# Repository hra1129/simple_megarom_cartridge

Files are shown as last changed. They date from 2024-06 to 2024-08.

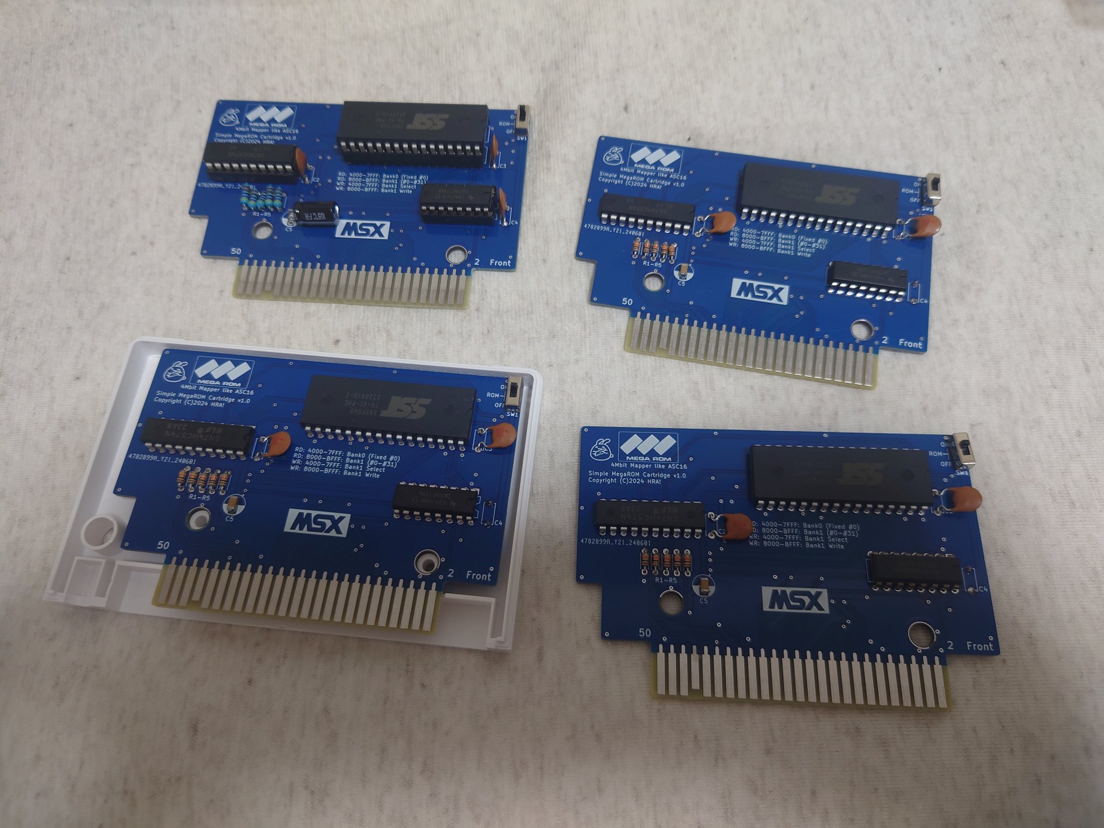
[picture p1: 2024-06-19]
image2.jpg

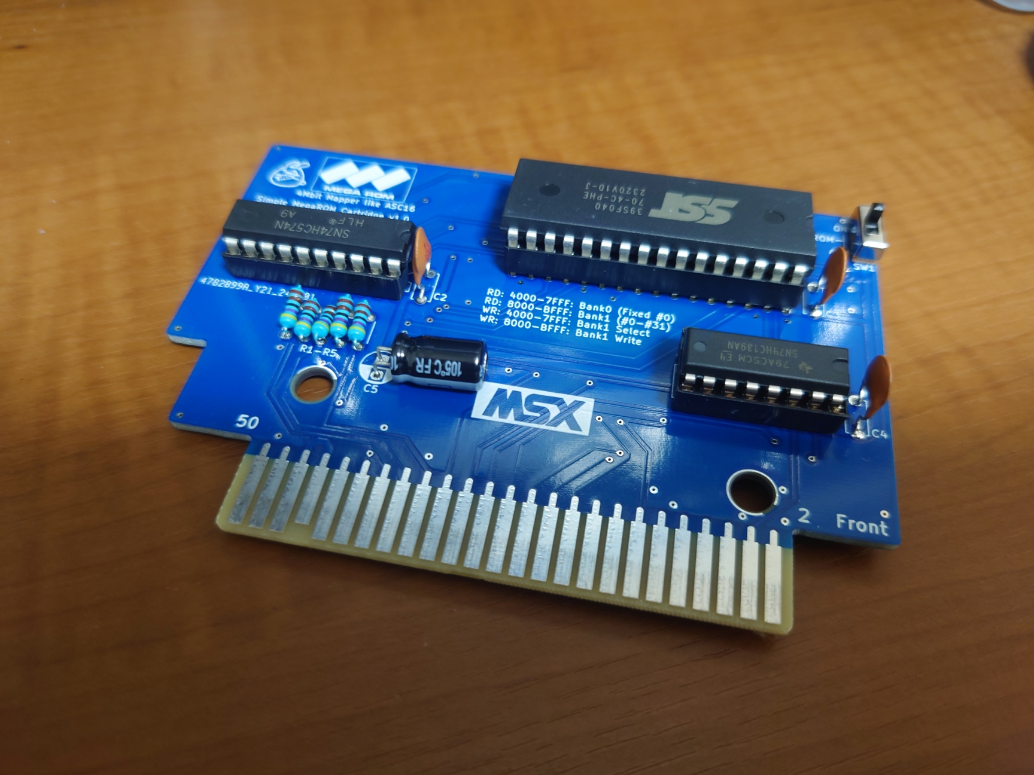
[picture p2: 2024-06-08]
image.jpg

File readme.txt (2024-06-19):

■概要
ASC16風のメガROMです。
ASC16風であって、ASC16ではないので、ASC16タイプの市販ゲームソフトを書き込んでも、
多くの場合、正常に動作しませんのでご注意下さい。
あくまで、自作ソフトを動かすためのメガROMコントローラーで、
安価に汎用部品で作りたい人向けです。

■免責事項
無保証です。
本情報に基づいた制作物に関して、何らかの不具合・不利益を被ったとしても、当方(HRA!/t.hara)は一切責任を負いません。
同意できる場合に限り、複製、改造等の派生、製造、配布、販売は自由に行って頂いて構いません。
動作確認などは各自で行った上で、各自の責任の下で配布・販売を行ってください。

■仕様
4000-7FFF が BANK0, 8000-BFFF が BANK1 になります。
BANK0への書き込みは、BANK1のバンクレジスタへの書き込みになります。
BANK1への書き込みは、BANK1のバンクレジスタの示すアドレスのROMへの書き込みになります。
BANK0の読み出しは、ROMのBANK#0の読み出しになります。
BANK1の読み出しは、BANK1のバンクレジスタの示すアドレスのROMの読み出しになります。
ROMのバンクは、BANK#0～#31 の 32通り。1バンク16KB になります。512KB の ROM の先頭から 16KBずつ区切り、
それを先頭から BANK#0, BANK#1, ... , BANK#31 と割り当てた番号になります。

C000-FFFF は BANK1のバンクレジスタのミラーになってます。ここに書き込んでもバンクが切り替わります。
といっても、通常、page3 は別スロットにある RAM を選択していると思いますので、ここへ書き込む使い方は
あまりオススメしません。

■ASC16との違い
(1) ASC16 は、BANK0 のバンクを切り替えることが出来ますが、本カートリッジでは BANK0 は BANK#0 固定です。
(2) ASC16 は、BANK1 のバンクはリセット時に BANK#0 に初期化されますが、初期バンク番号は本カートリッジでは不定です。
    必ずバンク番号を初期化してからアクセスしてください。
(3) ASC16 の BANK1 のバンクレジスタは 7000-77FF に存在しますが、本カートリッジでは 4000-7FFF が全てバンクレジスタです。

■コンセプト
4000-7FFF がバンクレジスタになっていますが、7000-77FF の範囲を使っていただくと、
OpenMSX等のエミュレーターを使って開発する際に、ASC16として設定すれば期待通り動作
するので、ASC16 に寄せた作りにしています。
それでいて、追加 IC は、汎用IC 2個だけで済ませました。
少ない汎用ICで、開発ツール類をそのまま利用できるメガROM、
というのがコンセプトになっております。

■基板の製造
(1) https://jlcpcb.com/ を webブラウザで開きます。
(2) 下記ファイルを Add Garber File にドラッグ＆ドロップします。
  /pcb/simple_megarom_cartridge/simple_megarom_cartridge.zip
(3) あとはサイトの指示に従って購入手続きを行うだけです。

基板の厚みは、デフォルトの 1.6mm にしてください。
カートリッジのカードエッジコネクタ部分は、基板の角をヤスリなどで斜めにカットすると MSX に挿入しやすくなります。
カートリッジは、部品面が前面です(MSXに装着したときに見える面)。
コナミタイプのカートリッジシェルに合わせた穴を開けてあります。
ICソケットを使うと、カートリッジシェルには収まらないのでご注意ください。

■書き込み
writer の中にある SMEGAWRT.COM を使うことで書き込むことが出来ます。
MSX-DOS上で、
  >SMEGAWRT TARGET.ROM
を実行すると、TARGET.ROM を書き込みます。

カートリッジ上のスイッチを切り替えることで、ROMを切り離すことが出来ます。
一度書き込んだあとに、別の内容に書き換える場合は、起動時に切り離しておいて、
MSX-DOSが起動してからスイッチを接続状態へ戻すことで書き替えることが出来ます。
切替スイッチが必要ない場合は、スイッチの接続用スルーホールの上2つをショートさせれば、常に接続状態になります。

-------------------------------------------------------------------------------
2024年6月 9日 初版 HRA!
2024年6月19日 追記 HRA!

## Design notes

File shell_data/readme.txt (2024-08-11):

ネジは、M2.6L12 をご使用ください。

https://wilco.jp/products/U/UF.html#page3
	UF-2612

JLCPCB で製造依頼する時は、上記にある 2つの STL ファイルを、アップロードして SLA(Rasin) → 9600 Rasin です。
Surface finish のところで、Spray Painting を選ぶと、色つけも可能です。
マットと光沢を選べるので、その辺拘りたい人も便利かもですね。

強度を確保するために、外装部分は厚めにしてあるため、
電解コンデンサなどかなり小型のタイプにしないと厳しいかもしれません。
高さ要注意です。

ネイル用リューターなどで削ることは出来るので、
微妙に足りない部分は、その部品の部分だけ内側削ってスペース確保してもいいかもしれません。
その辺はご自由に。

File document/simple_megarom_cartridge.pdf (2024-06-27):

# Simple MegaROM Cartridge

どんな MSX にも、4つの slot が存在します。これを基本スロットと呼びます。

0000h

3FFFh

page0

4000h

7FFFh

page1

8000h

BFFFh

page2

C000h

FFFFh

page3

slot0 | slot1 | slot2 | slot3

i8255(またはその互換回路)が搭載されており、その Port A と呼ばれる 8bit の記憶素子が I/O Port A8h に接続されています。 この 8bit は、2bit ずつ区切られていて、下位ビットから夫々 page0, page1, page2, page3 に選択される slot の番号になっています。

bit | 7 | 6 | 5 | 4 | 3 | 2 | 1 | 0

例えば、A8h が下記の値だった場合。

bit | 7 | 6 | 5 | 4 | 3 | 2 | 1 | 0
1 | 2 | 3 | 0

0000h

3FFFh

page0

4000h

7FFFh

page1

8000h

BFFFh

page2

C000h

FFFFh

page3

slot0 | slot1 | slot2 | slot3 | Z80から見える空間
0000h

3FFFh

page0

4000h

7FFFh

page1

8000h

BFFFh

page2

C000h

FFFFh

page3

Z80から見える空間は下記のようになります。

A8h を書き替えると、この構成は瞬時に切り替わります。
A8h は、通常は起動時に 00000000 に初期化されます。Z80 は起動時に 0000h から動き始めるので、 slot0 の page0 から動き始めることになります。普通の MSX は、そこに MAIN-ROM が接続されています。

MAIN-ROM

0000h

3FFFh

page0

MAIN-ROM

4000h

7FFFh

page1

RAM

8000h

BFFFh

page2

RAM

C000h

FFFFh

page3

slot0

SimpleMegaROM
bank0
BANK#0

SimpleMegaROM
bank1
BANK#??
slot1 | slot2 | slot3

# Simple MegaROM Cartridge 起動時の挙動

slot0 に MAIN-ROM と RAM、slot1 がカートリッジスロット、slot2 と slot3 は未使用の MSX を例に考えてみます。 カートリッジスロットに Simple MegaROM を接続している想定です。
赤く色が付いている page が、Z80 から見える空間だと思ってください。つまり、A8h で指定されている slot ですね。

起動時は下記のようになっています。

MAIN-ROM の page0 の方は、起動してすぐに割り込み禁止にして CHKRAM というルーチンに入り、RAM の存在する slot を 探し始めます。slot0 の page2, page3 に RAM が無い機種や、他の slot にもっと大容量の RAM がある場合もあるためです。 大容量の方を選択します。最大 32KB。
上記の構成の場合、slot0 の page2, page3 にしか RAM が存在しないので、page2, page3 は slot0 が選択され、
RAM が 32KB 見える状態になっています。

MAIN-ROM上のプログラム(BIOS)は、ここでようやく RAM が使えるようになるので、スタックポインタの初期化や、BIOSのため の RAM初期化を行います。

次に、全てのスロットの page1 を若い番号のスロットから順に調べていき、ROMカートリッジの存在をチェックします。 ROMカートリッジには、下記のようなヘッダ情報を書くルールになっており、BIOSはその先頭の 2byte である "AB" を調べること でROMカートリッジを検知します。

BIOS は、32KB 存在し、slot0 の page1 にも BIOSの後半が存在しています。
しかし、ここには "AB" は書かれていないため、ここを ROMカートリッジと誤認することはありません。 slot0 の次は、slot1 を調べます。
すると、SimpleMegaROM の bank0 が見えるようになります。
4000h | ID
4002h | INIT
4004h | STATEMENT
4006h | DEVICE
4008h | TEXT
400Ah | 予約
400Ch | 予約
400Eh | 予約

IDは、"AB" ( 41h, 42h ) を書く決まりになっています。
INIT は、そのカートリッジの初期化ルーチンのアドレスを書いておきます。ゲームならゲームの開始アドレスをここに書いておきます。 STATEMENT は、MSX-BASIC の CALL命令拡張を行う場合に、そのルーチンのアドレスを書いておく場所です。 DEVICE は、MSX-BASIC の OPEN "XXX:" のようなデバイス拡張を行う場合に、そのルーチンのアドレスを書いておく場所で す。
TEXT は、MSX-BASIC の BASICプログラムをROM化した場合に、そのアドレスを書いておく場所です。 いずれも、必要ない項目は 0000h を書いておけば無視されます。

MAIN-ROM

0000h

3FFFh

page0

MAIN-ROM

4000h

7FFFh

page1

RAM

8000h

BFFFh

page2

RAM

C000h

FFFFh

page3

slot0

SimpleMegaROM
bank0
BANK#0

SimpleMegaROM
bank1
BANK#??
slot1 | slot2 | slot3

BIOSは、slot1 の page1 を調べるために、page1 を slot1 に切り替えます。
BIOS も、Z80の機械語プログラムなので、当然 Z80の空間に出現させないとアクセス出来ないからです。

この状態で、bank#0 の先頭に "AB" が書いてあれば、SimpleMegaROM は「ROMカートリッジ」と認識して貰えます。 すると、次に INIT が 0000h でなければ、そこを CALL してくれるので、bank0 に出現している BANK#0 (4000h-7FFFh) を INIT に書いておけば、そこからゲームなどのプログラムを動かすことが出来るわけです。

ただ、注意しなければならないのは、page2 は RAM (slot0) が出現していて、bank1 (slot1) ではないという点です。 BANK#0 は、4000h-7FFFh に出現している前提で、「自分自身のスロットを調べるプログラム」を置いておく必要があります。 なぜならば、SimpleMegaROM が装着されている slot が slot1 とは限らないからです。
slot2 や slot3 かもしれませんし、拡張スロット上の slot1-1 かもしれません。(拡張スロットについては後ほど説明します。)

自分自身のスロットを調べるプログラムのサンプルは、後ほど提示します。 自分自身のスロットを見つけたら、必要に応じて page2 を SimpleMegaROM に切り替えて使うことになります。

SimpleMegaROM は、bank0 (page1)、bank1 (page2) が存在しますが、bank0 は BANK#0 固定です。
bank1 は、BANK#0～BANK#31 を選択して出現させられます。
bank0, bank1 ともに BANK#0 にすることもできます。

スロットの切替は、I/O の A8h を直接弄ることはオススメできません。BIOS に ENASLT, CALSLT, CALLF, RDSLT, WRSLT といったスロット操作の便利ルーチンが用意されているので、基本的にそちらを利用してください。特に、拡張スロットはこれを使わ ないととても大変です。

# Simple MegaROM Cartridge バンクの構成

Simple MegaROM は、512KB の ROM を搭載しており、これを 16KB単位で 32bank に分割管理されています。

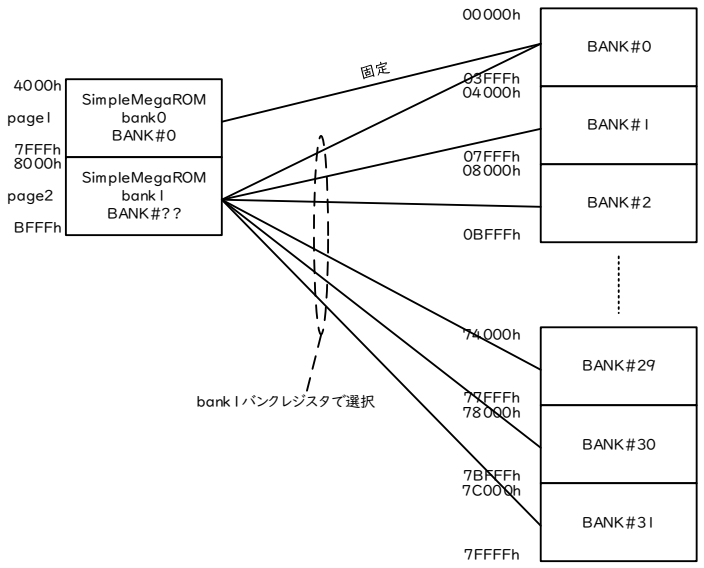
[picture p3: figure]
BANK#0; SimpleMegaROM bank0 BANK#0; SimpleMegaROM bank1 BANK#??; BANK#1; BANK#2; BANK#29; BANK#30; BANK#31; 03FFFh 04000h; 07FFFh 08000h; 0BFFFh; 7FFFFh; 7BFFFh; bank1バンクレジスタで選択; 77FFFh; 7FFFh; page1; BFFFh; page2

Simple MegaROM は、装着された slot の 0000h～FFFFh の空間を下記のように認識しています。

0000h

3FFFh

page0

4000h

7FFFh

page1

8000h

BFFFh

page2

C000h

FFFFh

page3

SimpleMegaROM
bank0
BANK#0

SimpleMegaROM
bank1
BANK#??

SimpleMegaROM
bank0ミラー
BANK#0

SimpleMegaROM
bank1ミラー
BANK#??

MSX本体は、i8255 portA によって選択されているスロット番号をデコードして、対応するスロットに /SLTSL = L を出すことで、 「あなたがアクセスされてますよ」と通知します。この信号は、全てのスロットに個別に存在しています。

## MSX本体の基本スロットの回路構成(抜粋)

## Z80は、プログラムコードや、データをメモリから読み書きする際に、そのアドレスを A0～A15 の 16bit で出力してきます。

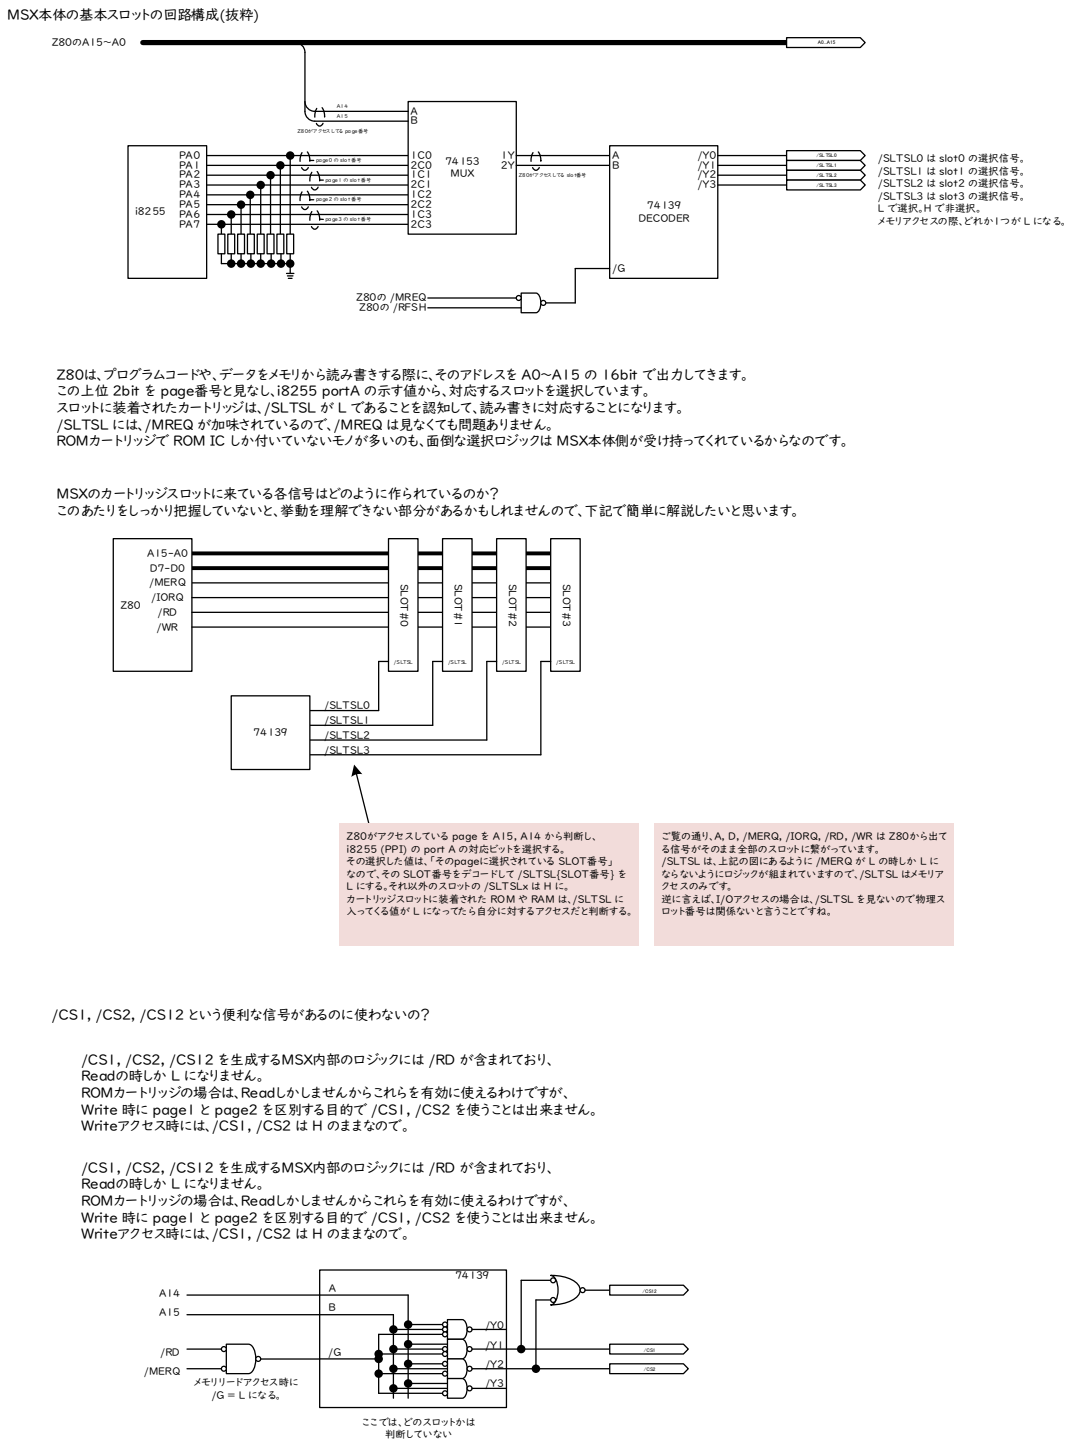
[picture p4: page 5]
page0 の slo t 番号; page1 の slo t 番号; page2 の slo t 番号; page3 の slo t 番号; 74153 MUX; Z80がアクセスしてる page番号; Z80がアクセスしてる slo t番号; 74139 DECODER; /SL TSL0; /SL TSL1; /SL TSL2; /SL TSL3; Z80の /MREQ Z80の /RFSH; /SLTSL0 は slot0 の選択信号。 /SLTSL1 は slot1 の選択信号。 /SLTSL2 は slot2 の選択信号。 /SLTSL3 は slot3 の選択信号。 L で選択。H で非選択。 メモリアクセスの際、どれか1つが L になる。; A15-A0 D7-D0 /MERQ /IORQ /RD /WR; SLOT#0; SLOT#1; SLOT#2; SLOT#3; /SLTSL0 /SLTSL1 /SLTSL2 /SLTSL3; /SLTSL; /CS1, /CS2, /CS12 という便利な信号があるのに使わないの？; /MERQ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

この上位 2bit を page番号と見なし、i8255 portA の示す値から、対応するスロットを選択しています。
スロットに装着されたカートリッジは、/SLTSL が L であることを認知して、読み書きに対応することになります。
/SLTSL には、/MREQ が加味されているので、/MREQ は見なくても問題ありません。
ROMカートリッジで ROM IC しか付いていないモノが多いのも、面倒な選択ロジックは MSX本体側が受け持ってくれているからなのです。

MSXのカートリッジスロットに来ている各信号はどのように作られているのか？
このあたりをしっかり把握していないと、挙動を理解できない部分があるかもしれませんので、下記で簡単に解説したいと思います。

Z80がアクセスしている page を A15, A14 から判断し、
i8255 (PPI) の port A の対応ビットを選択する。
その選択した値は、「そのpageに選択されている SLOT番号」
なので、その SLOT番号をデコードして /SLTSL{SLOT番号} を
L にする。それ以外のスロットの /SLTSLx は H に。
カートリッジスロットに装着された ROM や RAM は、/SLTSL に
入ってくる値が L になってたら自分に対するアクセスだと判断する。

ご覧の通り、A, D, /MERQ, /IORQ, /RD, /WR は Z80から出て
る信号がそのまま全部のスロットに繋がっています。
/SLTSL は、上記の図にあるように /MERQ が L の時しか L に
ならないようにロジックが組まれていますので、/SLTSL はメモリア
クセスのみです。
逆に言えば、I/Oアクセスの場合は、/SLTSL を見ないので物理ス
ロット番号は関係ないと言うことですね。

/CS1, /CS2, /CS12 を生成するMSX内部のロジックには /RD が含まれており、
Readの時しか L になりません。
ROMカートリッジの場合は、Readしかしませんからこれらを有効に使えるわけですが、
Write 時に page1 と page2 を区別する目的で /CS1, /CS2 を使うことは出来ません。
Writeアクセス時には、/CS1, /CS2 は H のままなので。

## SimpleMegaROM の挙動(1) [bank0のROM読み出し]

## ROMの A0～A13 はMSXのA0～A13 がそのまま接続されている。

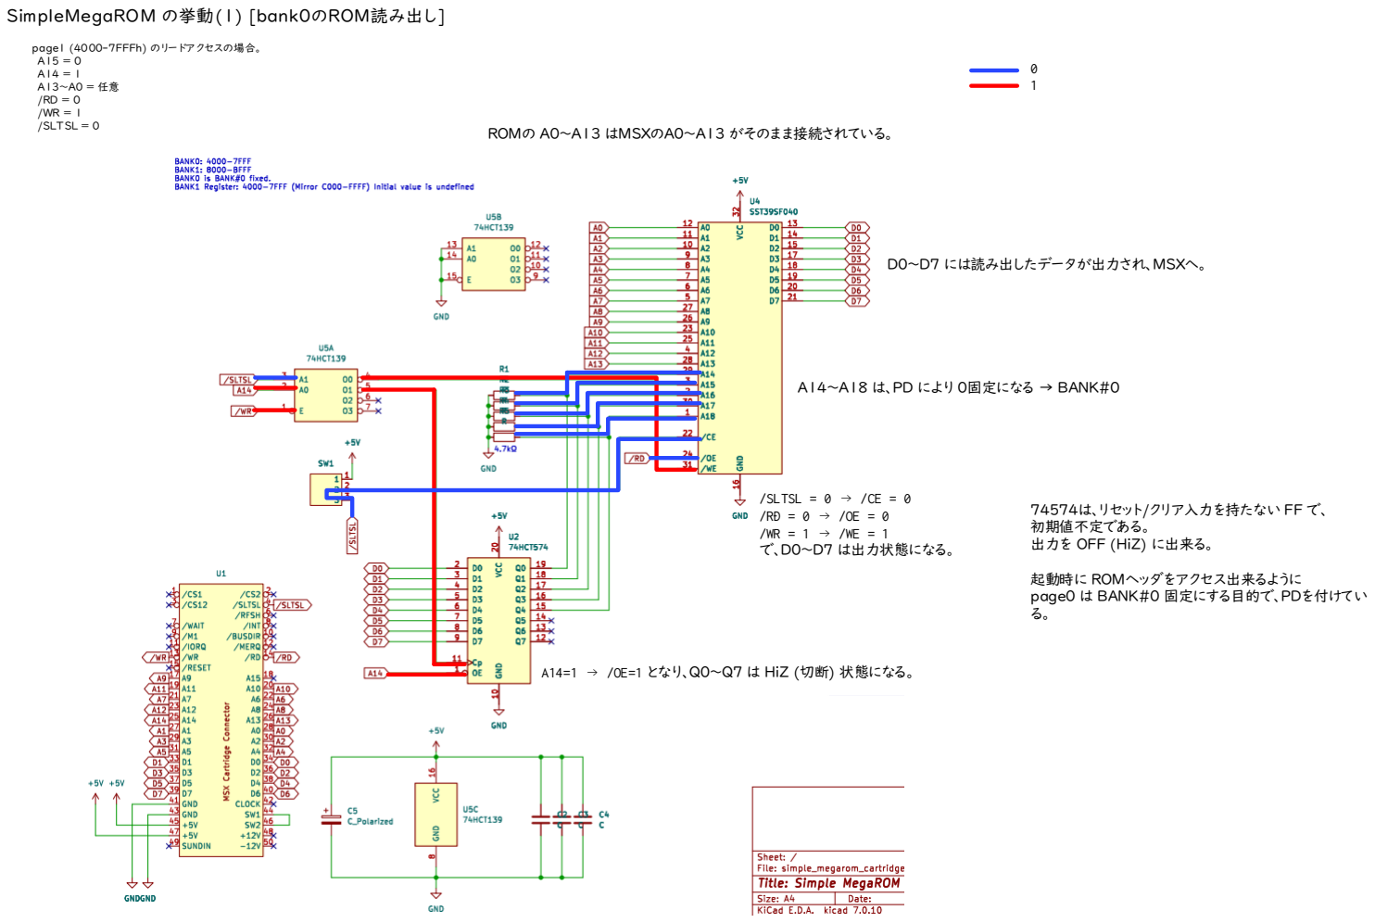
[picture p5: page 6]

page1 (4000-7FFFh) のリードアクセスの場合。 A15 = 0
A14 = 1
A13～A0 = 任意
/RD = 0
/WR = 1
/SLTSL = 0

## A14=1 → /OE=1 となり、Q0～Q7 は HiZ (切断) 状態になる。

## /SLTSL = 0 → /CE = 0 /RD = 0 → /OE = 0 /WR = 1 → /WE = 1 で、D0～D7 は出力状態になる。

## A14～A18 は、PD により 0固定になる → BANK#0

## 74574は、リセット/クリア入力を持たない FF で、

## 初期値不定である。

## 出力を OFF (HiZ) に出来る。

## 起動時に ROMヘッダをアクセス出来るように

## page0 は BANK#0 固定にする目的で、PDを付けてい

る。

## D0～D7 には読み出したデータが出力され、MSXへ。

1

0

## SimpleMegaROM の挙動(2) [bank1のROM読み出し]

## ROMの A0～A13 はMSXのA0～A13 がそのまま接続されている。

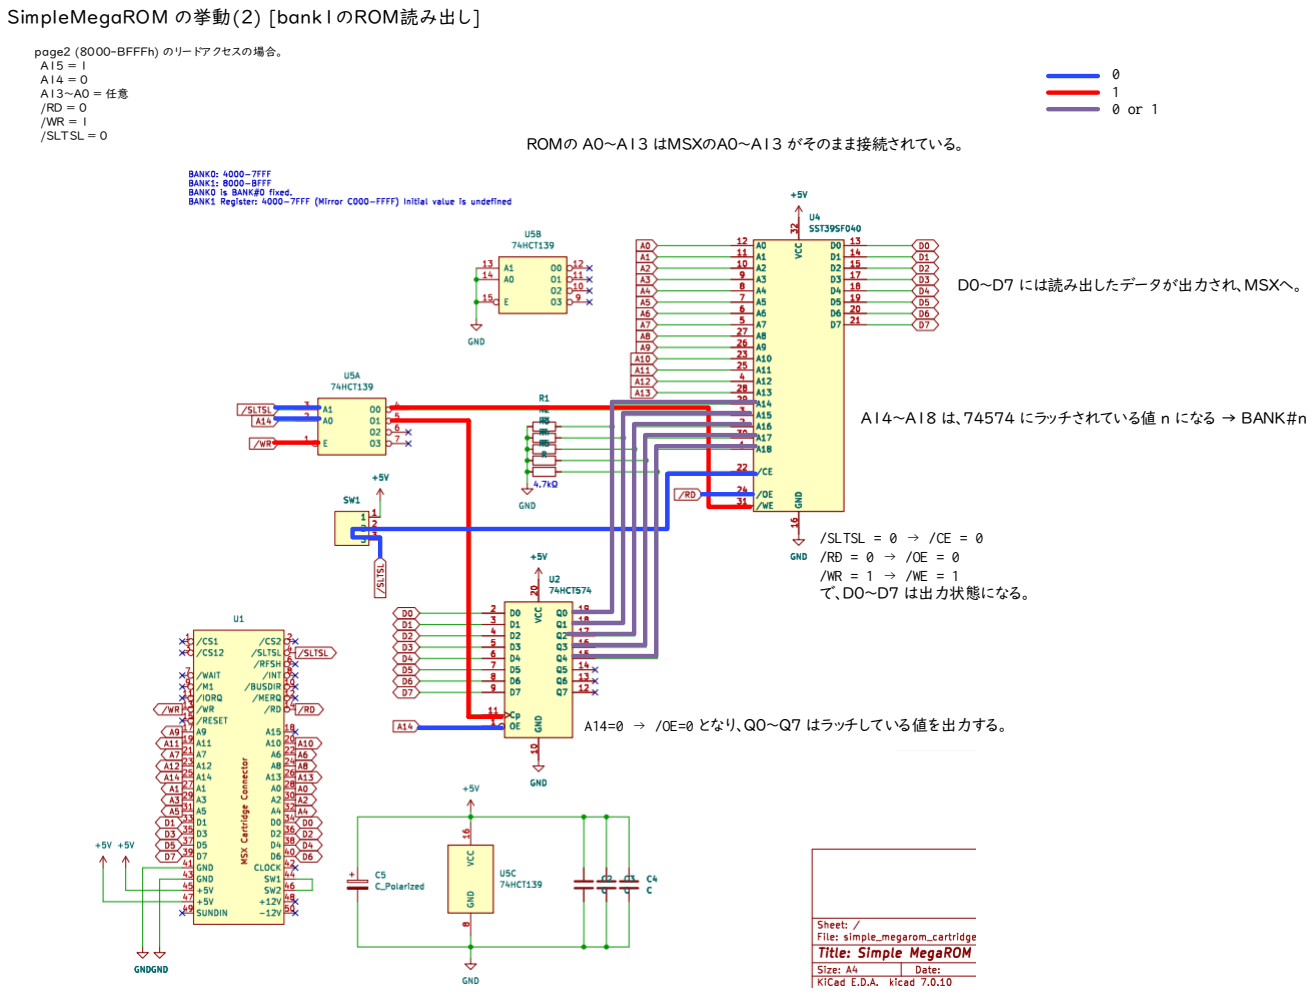
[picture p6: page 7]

page2 (8000-BFFFh) のリードアクセスの場合。 A15 = 1
A14 = 0
A13～A0 = 任意
/RD = 0
/WR = 1
/SLTSL = 0

## A14=0 → /OE=0 となり、Q0～Q7 はラッチしている値を出力する。

## /SLTSL = 0 → /CE = 0 /RD = 0 → /OE = 0 /WR = 1 → /WE = 1 で、D0～D7 は出力状態になる。

## A14～A18 は、74574 にラッチされている値 n になる → BANK#n

## D0～D7 には読み出したデータが出力され、MSXへ。

1

0

0 or 1

## SimpleMegaROM の挙動(3) [バンクレジスタへの書き込み]

## ROMの A0～A13 はMSXのA0～A13 がそのまま接続されている。

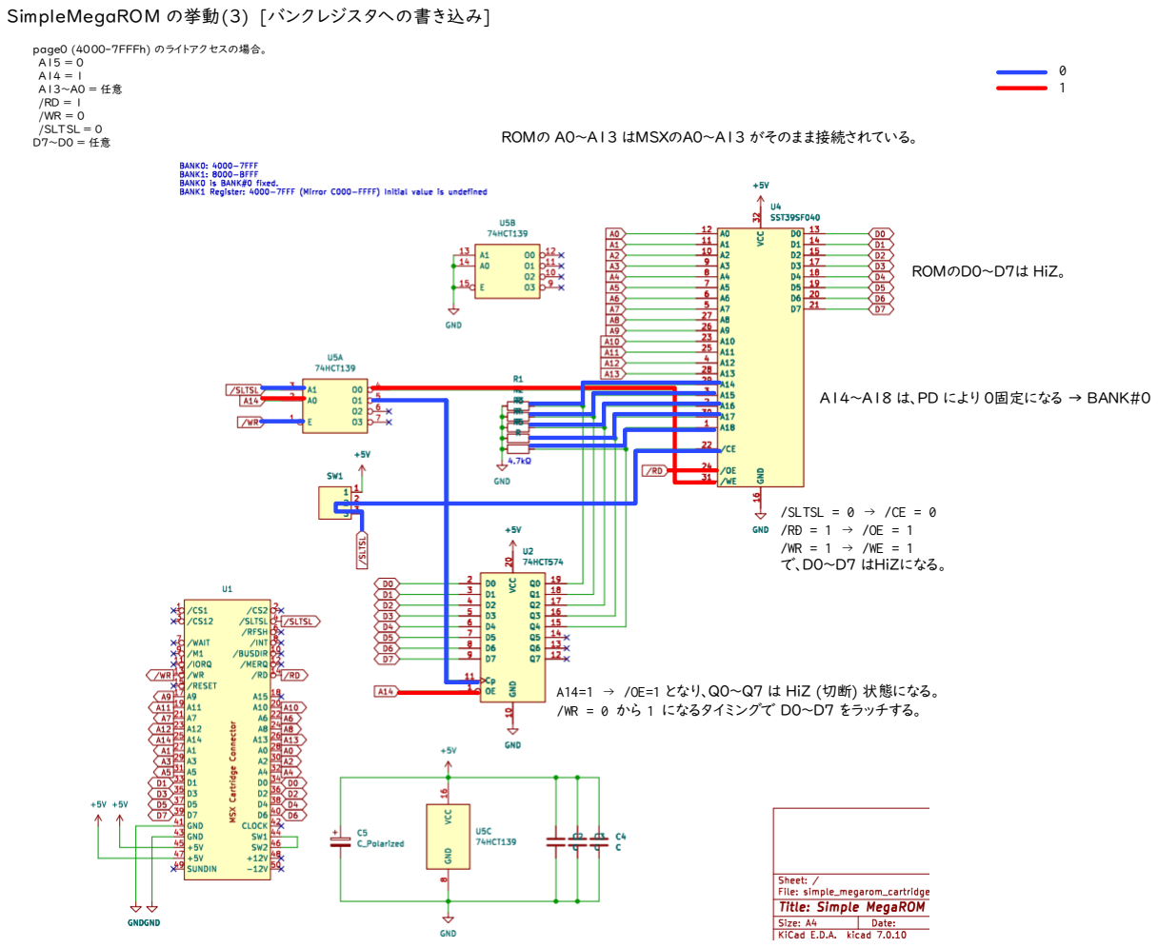
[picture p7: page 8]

page0 (4000-7FFFh) のライトアクセスの場合。 A15 = 0
A14 = 1
A13～A0 = 任意
/RD = 1
/WR = 0
/SLTSL = 0
D7～D0 = 任意

## A14=1 → /OE=1 となり、Q0～Q7 は HiZ (切断) 状態になる。 /WR = 0 から 1 になるタイミングで D0～D7 をラッチする。

## /SLTSL = 0 → /CE = 0 /RD = 1 → /OE = 1 /WR = 1 → /WE = 1 で、D0～D7 はHiZになる。

## A14～A18 は、PD により 0固定になる → BANK#0

## ROMのD0～D7は HiZ。

1

0

## SimpleMegaROM の挙動(4) [bank1のROM書き込み]

## ROMの A0～A13 はMSXのA0～A13 がそのまま接続されている。

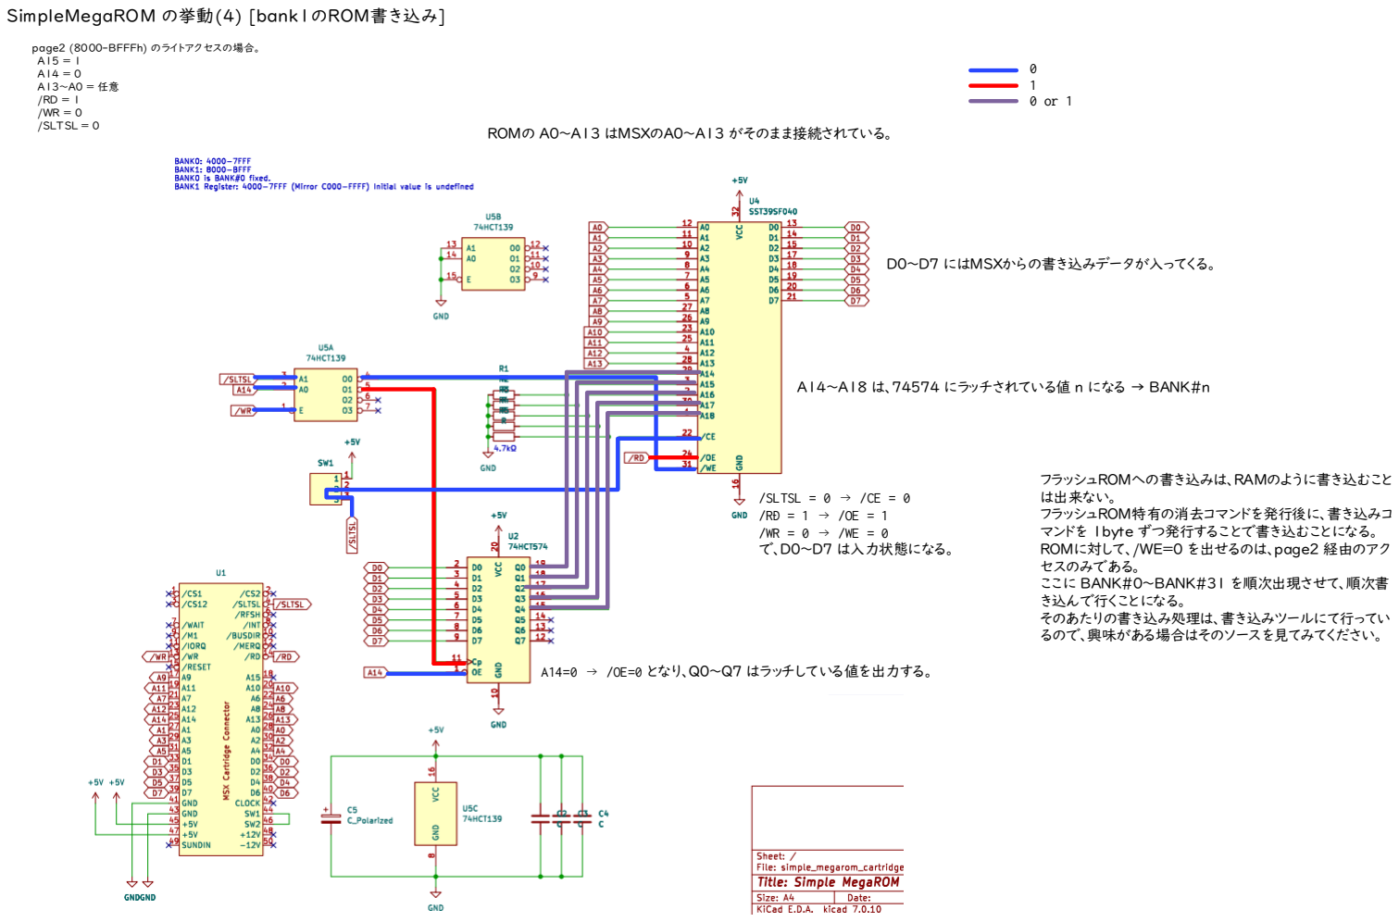
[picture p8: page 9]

page2 (8000-BFFFh) のライトアクセスの場合。 A15 = 1
A14 = 0
A13～A0 = 任意
/RD = 1
/WR = 0
/SLTSL = 0

## A14=0 → /OE=0 となり、Q0～Q7 はラッチしている値を出力する。

## /SLTSL = 0 → /CE = 0 /RD = 1 → /OE = 1 /WR = 0 → /WE = 0 で、D0～D7 は入力状態になる。

## A14～A18 は、74574 にラッチされている値 n になる → BANK#n

## D0～D7 にはMSXからの書き込みデータが入ってくる。

1

0

0 or 1

## フラッシュROMへの書き込みは、RAMのように書き込むこと

## は出来ない。

## フラッシュROM特有の消去コマンドを発行後に、書き込みコ

## マンドを 1byte ずつ発行することで書き込むことになる。 ROMに対して、/WE=0 を出せるのは、page2 経由のアク

## セスのみである。

## ここに BANK#0～BANK#31 を順次出現させて、順次書

## き込んで行くことになる。

## そのあたりの書き込み処理は、書き込みツールにて行ってい

## るので、興味がある場合はそのソースを見てみてください。

## SimpleMegaROM の挙動(5) [ミラー]

回路図を見て分かるとおり、A15 は全く使用していないため、page0 と page2, page1とpage3 は全く区別していません。 つまり、page0 へのアクセスは page2 へのアクセスと同じ意味を持ちます。
また、page3へのアクセスは page1 へのアクセスと同じ意味を持ちます。
通常、起動時には page0 は BIOS が、page3 はスタックを置いているRAMのスロットを選択している状態であり、
特に page3 を切り替えることは殆ど無いため、これを敢えてミラーとして使う事は無いでしょう(使っても良いですけど）。

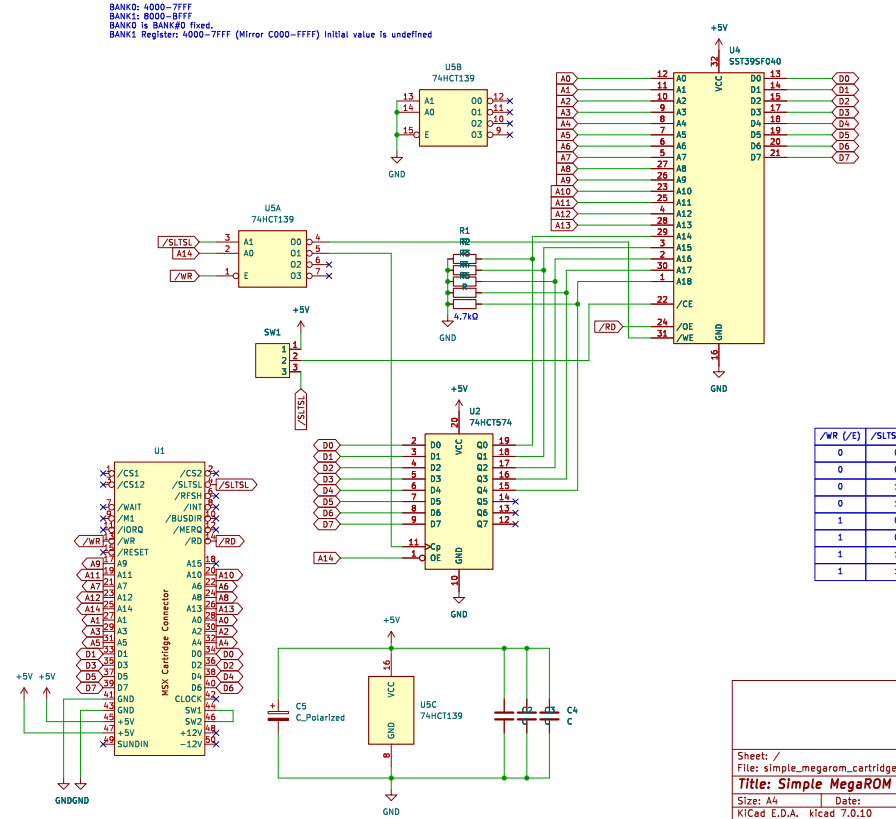
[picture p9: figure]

# MSXの拡張スロット

0000h

3FFFh

page0

4000h

7FFFh

page1

8000h

BFFFh

page2

C000h

FFFFh

page3

slot0 | slot1 | slot2 | slot3

MSXには、拡張スロットという仕組みも定義されています。
例えば、slot1 に拡張スロットが装着されている場合、下記のようなイメージになります。
slot1-0 | slot1-1 | slot1-2 | slot1-3
| FF

拡張スロット選択レジスタ (FFFFh)

拡張スロットが接続されているスロットに対して、メモリアクセスで FFFFh 番地にアクセスすると拡張スロット選択レジスタにアクセ ス出来ます。
このレジスタは、8bit の値を持ち、2bit 単位で区切られており、下位ビットから page0, page1, page2, page3 の拡張スロット 番号を保持しています。
この拡張スロット選択レジスタで選択されている拡張スロットが、装着されている基本スロットから見える形になります。

拡張スロット選択レジスタは、読み出すことも出来ます。読み出すと全ビット反転して読み出されます。

反転されるのは、「拡張スロット選択レジスタですよ！」との意味を示しています。
そのまま読めてしまうと、単なる RAMカートリッジが基本スロットに直接刺さっている場合に、RAMだから書いた値が読めたのか、 拡張スロット選択レジスタだから書いた値が読めたのか、区別できないためですね。書いた値の反転が読めれば、拡張スロット選 択レジスタと判定できるわけです。

そして、拡張スロットの page3 にどのスロットが選択されていても、FFFFh に対するアクセスは拡張スロット選択レジスタになりま す。
つまり、拡張スロットに装着した ROMやRAMの FFFFh にはアクセス出来ません。
各拡張スロットにも /SLTSL0～3 (この 0～3 は基本スロットではなく拡張スロットの番号）が存在していて、それが L になってい るスロットにアクセスすることになりますが、FFFFh だけは、この信号がでません。拡張スロット選択レジスタの回路が遮断します。

例えば、MapperRAM のように、16KB単位のRAMを任意の page に出現させられるようなモノの場合、拡張スロット切替の度に FFFFh に出現しているマッパーセグメント（MapperRAMのバンクのようなモノ）の FFFFhが拡張スロット番号で上書きされると、 そのセグメントを別のpageに出現させたときにそこが壊れている状態になってしまうためです。なので、遮断されるように拡張スロッ トは作られています。

後期のMSXでは、本体内は、拡張スロットになっているのが当たり前の状態になっていました。MAIN-ROM でさえ、SLOT#0-0 に装着されている状態ですね。

## 2024年6月21日 HRA!

# Simple MegaROM上のプログラムで自身のスロットを検出する

.org 4000h
.db | 41h, 42h ; ID
.dw | init | ; INIT
.dw | 0 | ; STATEMENT
.dw | 0 | ; DEVICE
.dw | 0 | ; TEXT
.dw | 0 | ; Reserved
.dw | 0 | ; Reserved
.dw | 0 | ; Reserved

init:
; ROM のスロットを調べる
di
in | a, (0A8h) | ; 現在このプログラムがある page1 のスロットを調べる
rrca
rrca
and | a, 3
ld | (romslt), a
add | a, 0C1h
ld | h, 0FCh
ld | l, a
ld | a, (hl) | ; EXTTBL を見る
and | a, 80h
jr | z, no_extslt
inc | hl
inc | hl
inc | hl
inc | hl
ld | a, (hl) | ; 拡張スロット選択レジスタ
and | a, 0Ch
ld | b, a
ld | a, (romslt)
or | a, b
or | a, 80h
ld | (romslt), a
no_extslt:
ld a, (romslt)
; PAGE1 をカートリッジのスロットにする
ld h, 80h
call enaslt

MSXのBIOS には、スロット切替のためのルーチンが用意されていて、これを利用することによって面倒なスロット切替を、簡単に行える。 しかし、残念ながら現在のスロット番号を得るルーチンは用意されていない。

現在の基本スロットの番号を得るためには、I/O A8h を読む必要がある。
現在の拡張スロットの番号を得る場合は、ワークエリア SLTTBL (FCC5h) にバックアップが書き込まれているので、そこを参照すれば良い。

FCC5h ... slot#0の拡張スロット番号
FCC6h ... slot#1の拡張スロット番号
FCC7h ... slot#2の拡張スロット番号
FCC8h ... slot#3の拡張スロット番号

この拡張スロット番号は、2bit ずつ区切られていて、下位から page0, page1, page2, page3 の拡張スロット番号になっている。

bit | 7 | 6 | 5 | 4 | 3 | 2 | 1 | 0
pa ge3 | pa ge2 | pa ge1 | pa ge0

さらに、各スロットが拡張されているか否かも、BIOS のワークエリア EXPTBL(FCC1h) に記録されている。

FCC1h ... MSB 1bit が 1 なら slot0 は拡張されている
FCC2h ... MSB 1bit が 1 なら slot1 は拡張されている
FCC3h ... MSB 1bit が 1 なら slot2 は拡張されている
FCC4h ... MSB 1bit が 1 なら slot3 は拡張されている
bit | 7 | 6 | 5 | 4 | 3 | 2 | 1 | 0

0: 拡張されていない, 1: 拡張されている

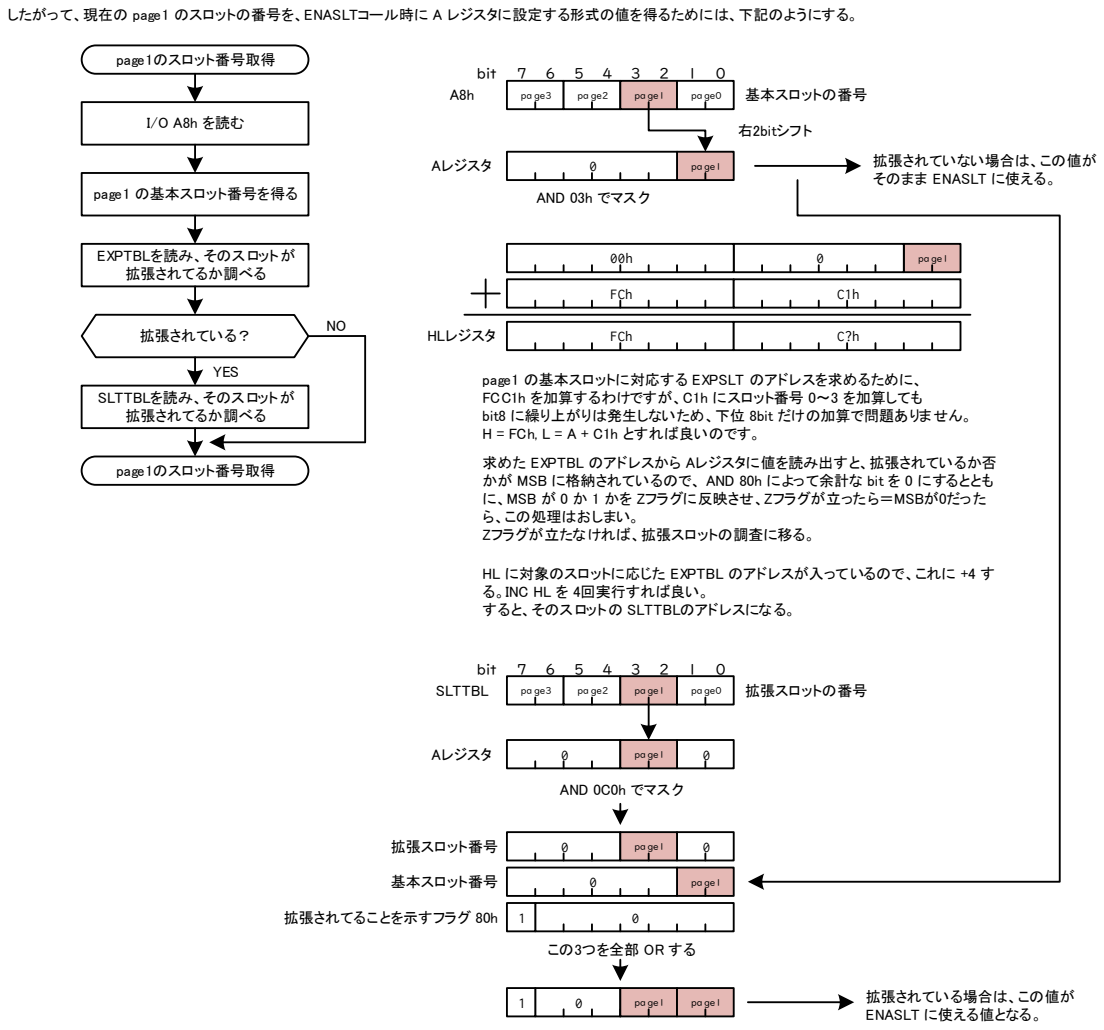
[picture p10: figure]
したがって、現在の page1 のスロットの番号を、ENASLTコール時に A レジスタに設定する形式の値を得るためには、下記のようにする。; page1のスロット番号取得; I/O A8h を読む; page1 の基本スロット番号を得る; EXPTBLを読み、そのスロットが 拡張されてるか調べる; 拡張されている？; YES; SLTTBLを読み、そのスロットが 拡張されてるか調べる; bit; 右2bitシフト; AND 03h でマスク; 拡張されていない場合は、この値が そのまま ENASLT に使える。; FCh; page1 の基本スロットに対応する EXPSLT のアドレスを求めるために、 FCC1h を加算するわけですが、C1h にスロット番号 0～3 を加算しても bit8 に繰り上がりは発生しないため、下位 8bit だけの加算で問題ありません。 H = FCh, L = A + C1h とすれば良いのです。; Aレジスタ; HLレジスタ; 求めた EXPTBL のアドレスから Aレジスタに値を読み出すと、拡張されているか否; ら、この処理はおしまい。 Zフラグが立たなければ、拡張スロットの調査に移る。; る。INC HL を 4回実行すれば良い。 すると、そのスロットの SLTTBLのアドレスになる。; 基本スロットの番号; SLTTBL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

かが MSB に格納されているので、 AND 80h によって余計な bit を 0 にするととも に、MSB が 0 か 1 かを Zフラグに反映させ、Zフラグが立ったら＝MSBが0だった

HL に対象のスロットに応じた EXPTBL のアドレスが入っているので、これに +4 す

# ROMの INIT が呼ばれたタイミングのスロット状態の例

FS-A1ST/A1GT、カートリッジスロット1 に ROMを装着した場合

Z80/R800から見える空間
0000h

3FFFh

page0

4000h

7FFFh

page1

8000h

BFFFh

page2

C000h

FFFFh

page3

slot0-0
MAIN-ROM

slot3-1
RAM

slot3-1
RAM

slot1
カートリッジ

FS-A1ST/A1GT、カートリッジスロット2 に ROMを装着した場合

Z80/R800から見える空間
0000h

3FFFh

page0

4000h

7FFFh

page1

8000h

BFFFh

page2

C000h

FFFFh

page3

slot0-0
MAIN-ROM

slot3-1
RAM

slot3-1
RAM

slot2
カートリッジ

PV-7、カートリッジスロット に ROMを装着した場合

Z80から見える空間
0000h

3FFFh

page0

4000h

7FFFh

page1

8000h

BFFFh

page2

C000h

FFFFh

page3

slot0-0
MAIN-ROM

slot0
RAM

slot3-1
RAM

slot1
カートリッジ

slot0
未接続

この機種だけ特殊で RAM が 8KB しかない。
page3 の後半半分(E000h-FFFFh)だけ 8KB の RAM が見えている状態。
従って、全ての MSX に対応させるためには、RAM は E000h-FFFEh しか使えない。
FFFFh は拡張スロットレジスタの可能性があるので、 RAMとして使用してはならない。

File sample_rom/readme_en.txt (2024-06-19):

Sample MegaROM Program
-------------------------------------------------------------------------------

This is a sample program to check the operation of the MegaROM I made.
It speaks using PSG. (*Some machines with a PSG-compatible sound source do not produce sound, e.g. MX-101)

VOICEVOX: Nekotsuka Bii was used for the audio.
https://voicevox.hiroshiba.jp/

Please note that you must abide by the terms of Nekotsuka Bii's license agreement regarding the use of audio.
https://nekotukarb.wixsite.com/nekonohako/%E5%88%A9%E7%94%A8%E8%A6%8F%E7%B4%84

Video of it in action.
https://x.com/thara1129/status/1803029993166921950

If you want to run it on an emulator, select an ASCII16 type megacomputer.

-------------------------------------------------------------------------------
June/19th/2024 t.hara (HRA!)

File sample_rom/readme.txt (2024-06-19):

Sample MegaROM Program
-------------------------------------------------------------------------------

作った MegaROM の動作を確認するためのサンプルプログラムです。
PSG を使って喋ります。( ※一部の PSG互換音源搭載機では音声が出ません。MX-101 等）

音声は、VOICEVOX: 猫使ビィさんを使わせていただきました。
https://voicevox.hiroshiba.jp/

音声の利用に関しては、猫使ビィさんのライセンス規約を守る必要がありますのでご注意ください。
https://nekotukarb.wixsite.com/nekonohako/%E5%88%A9%E7%94%A8%E8%A6%8F%E7%B4%84

動作している動画
https://x.com/thara1129/status/1803029993166921950

エミュレーターで動かす場合は、ASCII16タイプのメガコンを選択してください。

-------------------------------------------------------------------------------
2024/06/18 t.hara (HRA!)
2024/06/19 t.hara (HRA!) 追記

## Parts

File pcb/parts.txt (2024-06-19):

基板に取り付ける部品
	U2 ......... 74HC574
	U4 ......... SST39SF040A
	U5 ......... 74HC139
	C2,C3,C4 ... 0.1uF
	R1-R5 ...... 4.7KΩ～10kΩ ※全部同じ抵抗値にすること
	C5 ......... 100uF
	SW1 ........ スイッチ

入手先参考
	74HC574
		https://www.digikey.jp/ja/products/detail/texas-instruments/SN74HC574N/277244
	SST39SF040A
		https://www.digikey.jp/ja/products/detail/microchip-technology/SST39SF040-70-4C-PHE/2297835
	74HC139
		https://www.digikey.jp/ja/products/detail/texas-instruments/SN74HC139N/376908
	0.1uF
		https://akizukidenshi.com/catalog/g/g104064/
	4.7KΩ
		https://akizukidenshi.com/catalog/g/g125472/
	100uF
		https://akizukidenshi.com/catalog/g/g110271/
		→ 取り付けやすいが、シェルに収まらない。
		https://akizukidenshi.com/catalog/g/g106055/
		→ 取り付けはちょっとだけ難しいが、シェルに収まる。
	スイッチ
		https://akizukidenshi.com/catalog/g/g115707/
	カートリッジシェル
		https://www.kadenken.com/view/item/000000001496

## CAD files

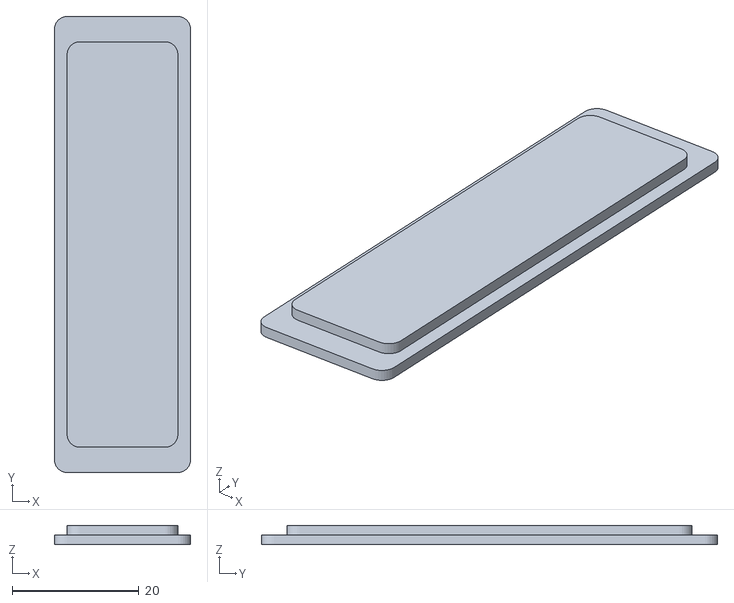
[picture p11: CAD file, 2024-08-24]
shell_data/big/MSX_cartridge_big_shell_panel.stl
21.5 x 72.0 x 3.00

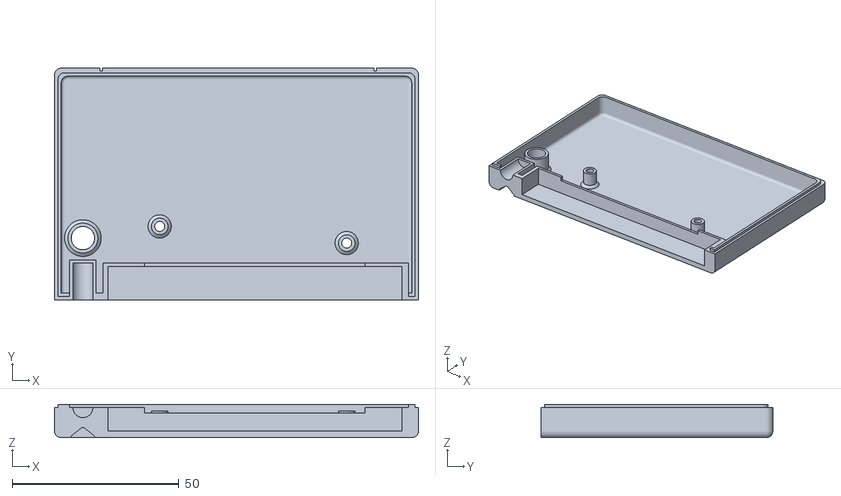
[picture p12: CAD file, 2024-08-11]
shell_data/standard/MSX_cartridge_shell_back.stl
109.0 x 69.4 x 10.0

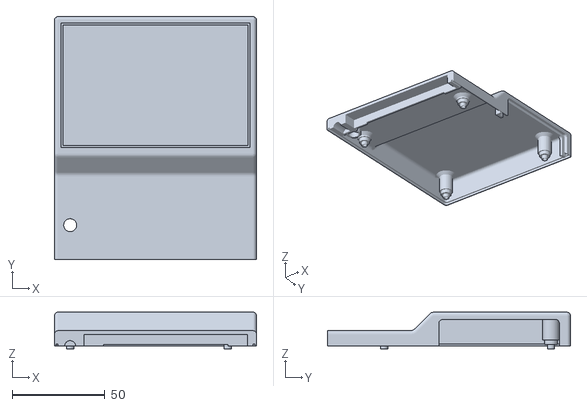
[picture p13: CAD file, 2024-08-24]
shell_data/big/MSX_cartridge_big_shell_front.stl
109.0 x 131.0 x 19.8

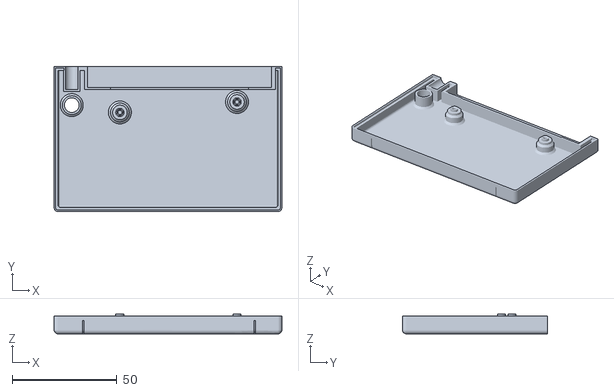
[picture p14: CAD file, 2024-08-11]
shell_data/standard/MSX_cartridge_shell_front.stl
109.0 x 69.4 x 9.50

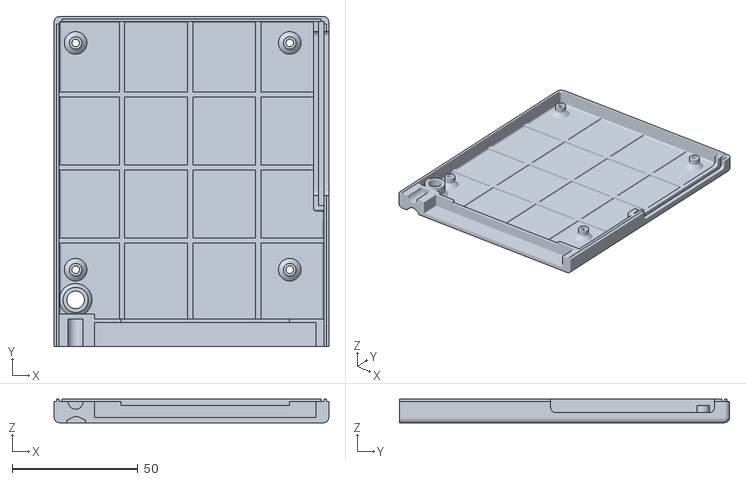
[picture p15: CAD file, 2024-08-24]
shell_data/big/MSX_cartridge_big_shell_back.stl
109.0 x 131.0 x 9.35

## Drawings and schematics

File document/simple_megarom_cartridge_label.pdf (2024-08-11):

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

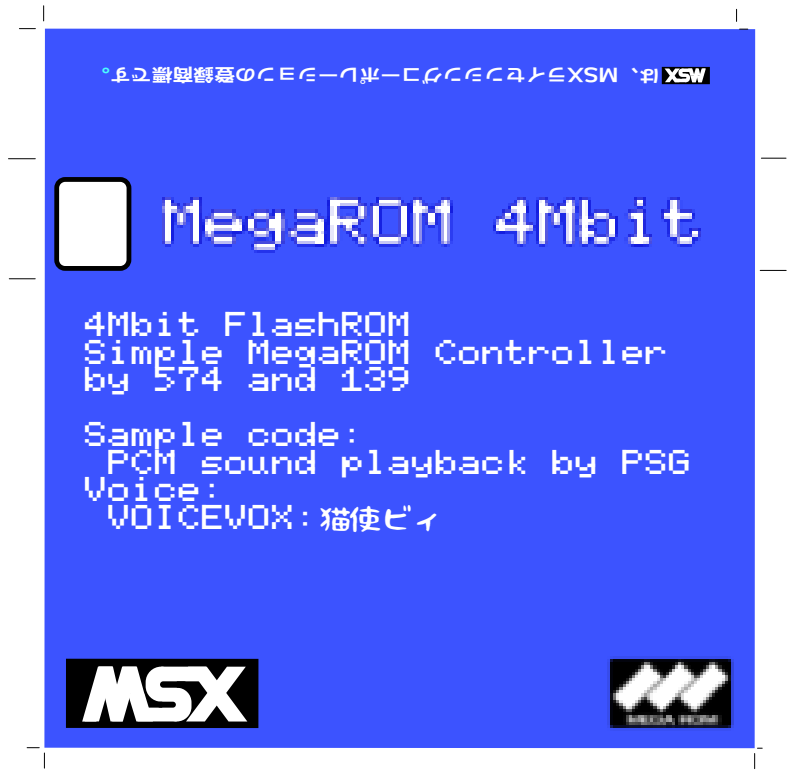
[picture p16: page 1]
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

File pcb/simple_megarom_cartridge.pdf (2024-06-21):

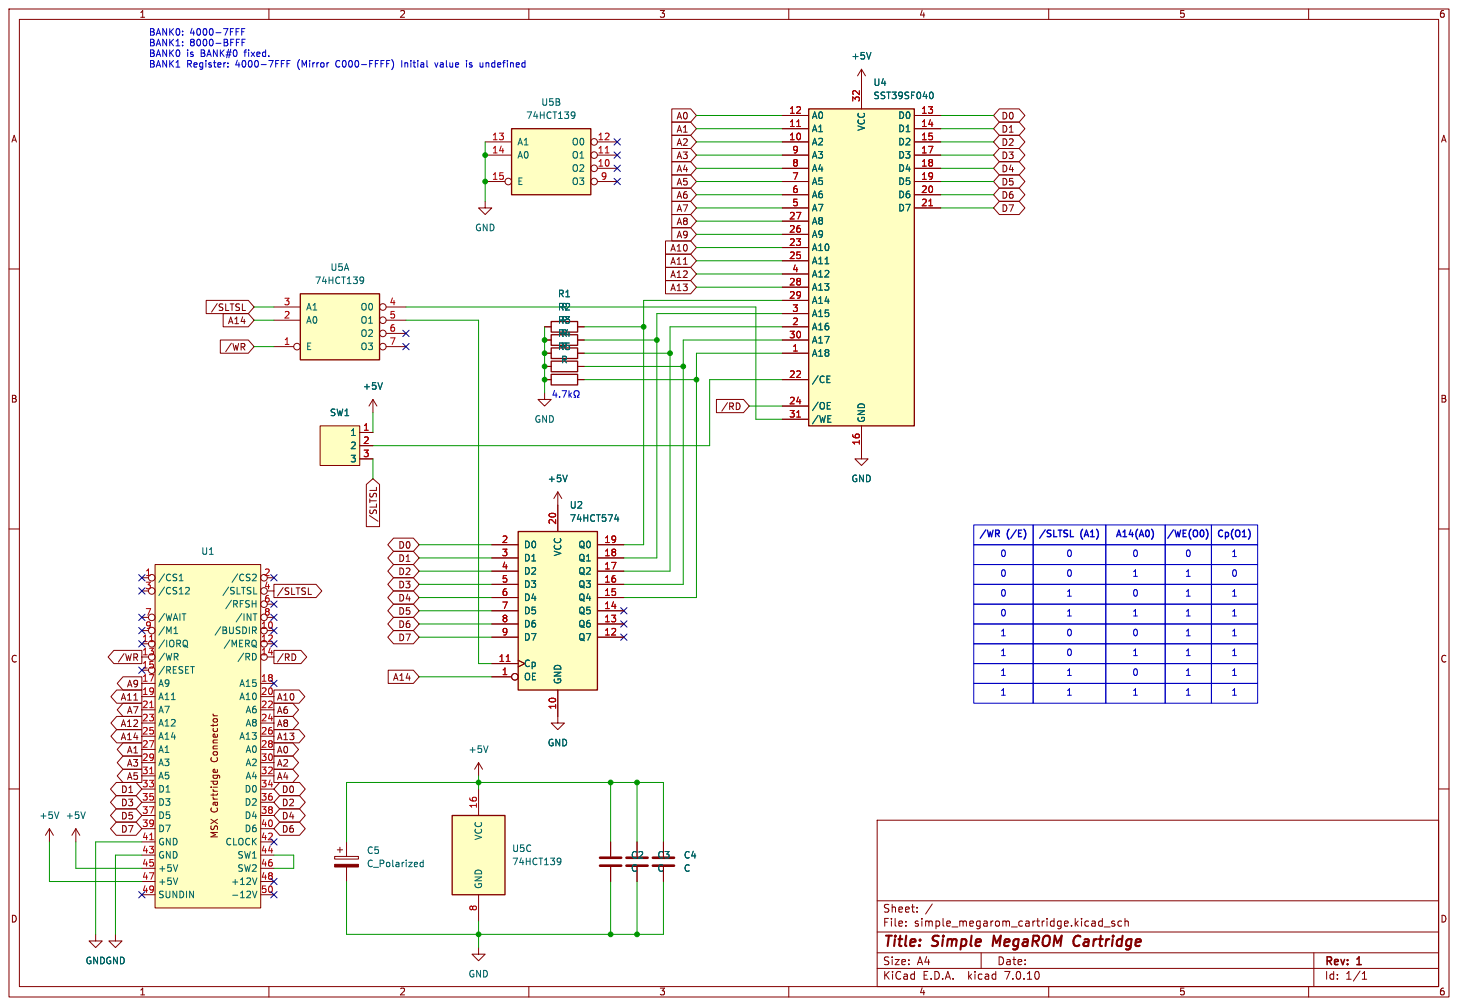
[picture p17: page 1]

Id: 1/1 Title: Simple MegaROM Cartridge

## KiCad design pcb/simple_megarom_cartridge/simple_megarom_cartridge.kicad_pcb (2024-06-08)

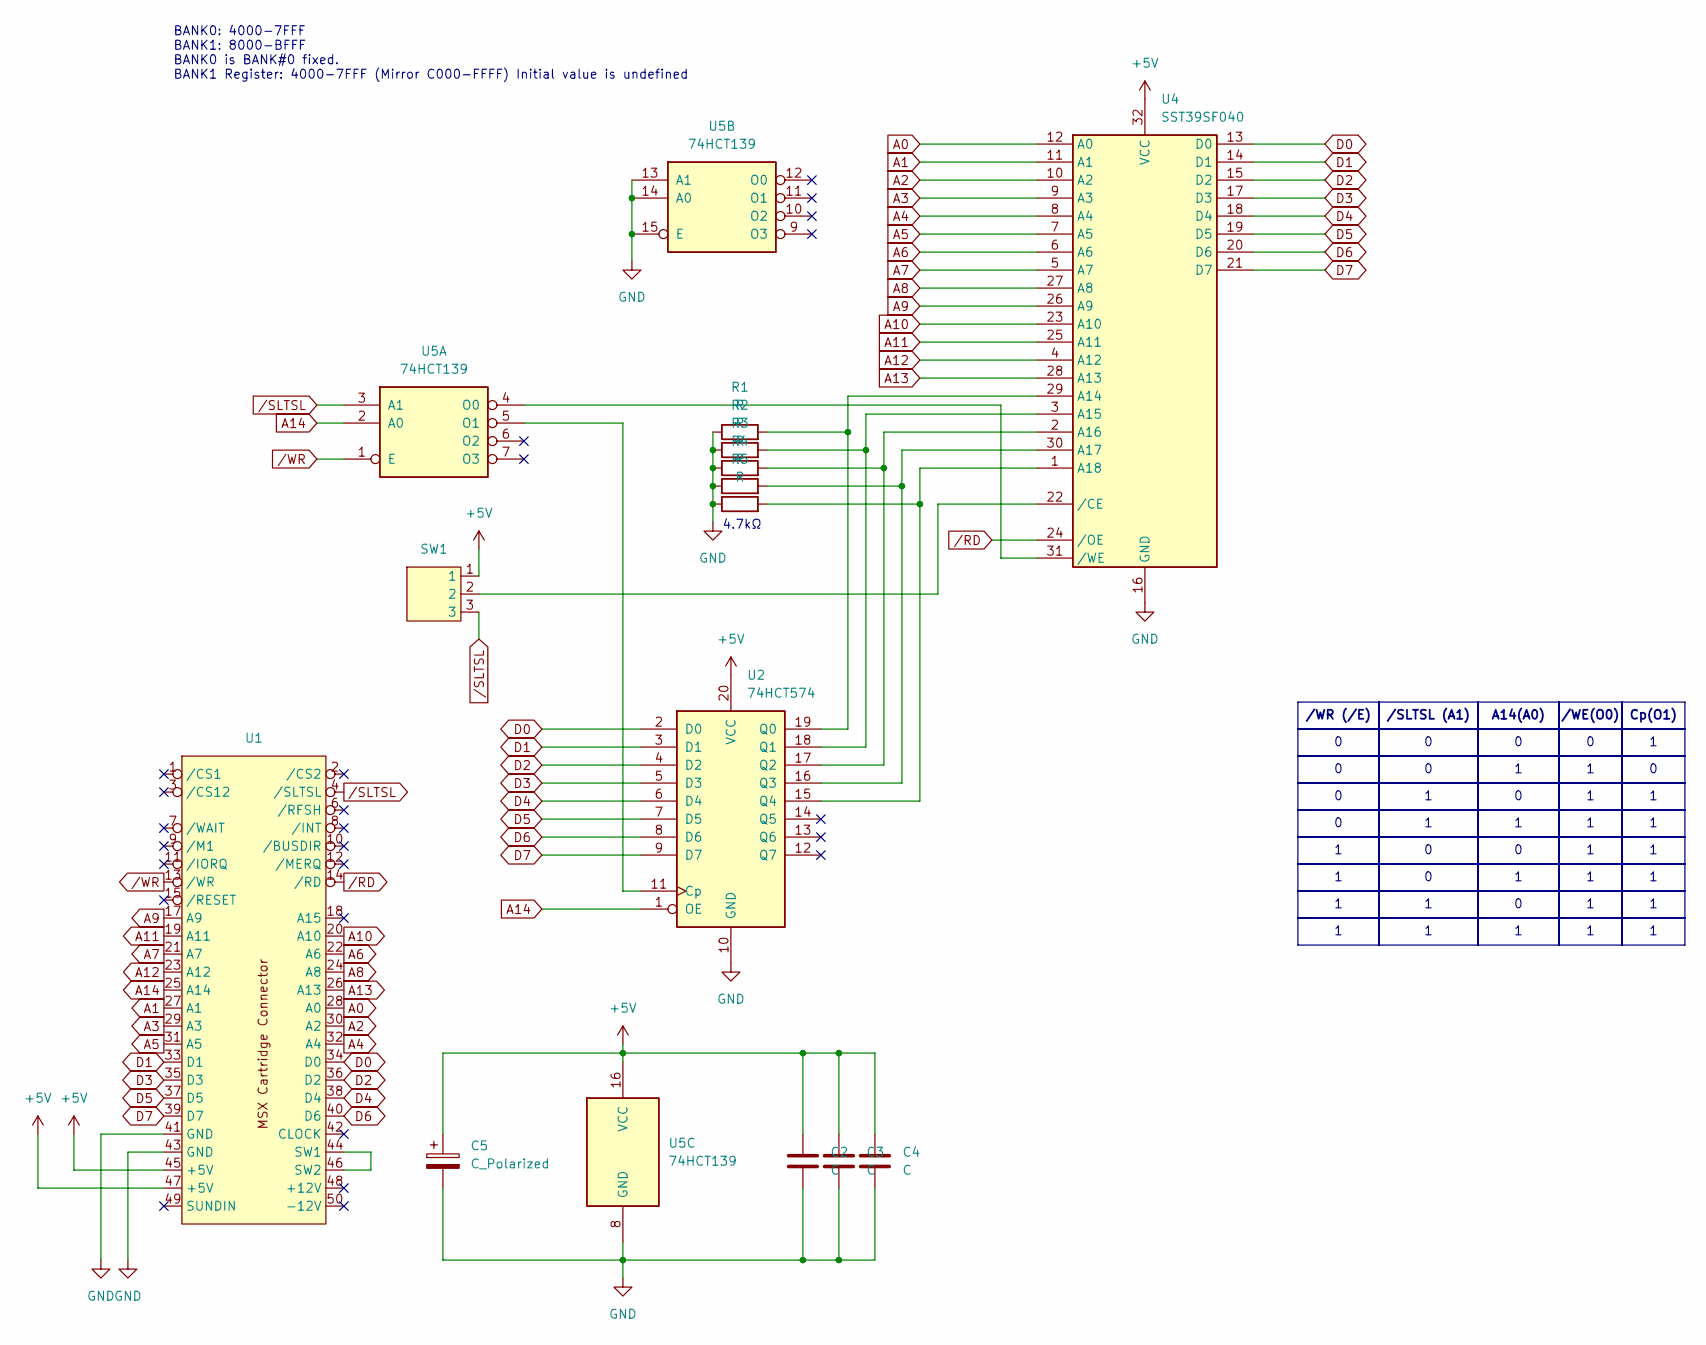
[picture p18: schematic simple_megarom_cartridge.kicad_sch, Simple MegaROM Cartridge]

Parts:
C2, C3, C4: C; C_Disc_D5.0mm_W2.5mm_P5.00mm
C5: C_Polarized; CP_Radial_D5.0mm_P2.50mm
R1, R2, R3, R4, R5: R; R_Axial_DIN0204_L3.6mm_D1.6mm_P5.08mm_Horizontal
SW1: PinHeader_1x03_P2.54mm_Vertical
U1: MSX Cartridge_1
U2: 74HCT574; DIP-20_W7.62mm
U4: SST39SF040; DIP-32_W15.24mm
U5: 74HCT139; DIP-16_W7.62mm

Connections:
+5V: C2.1, C3.1, C4.1, C5.1, SW1.1, U1.45 (+5V), U1.47 (+5V), U2.20 (VCC), U4.32 (VCC), U5.16 (VCC)
A0: U1.28 (A0), U4.12 (A0)
A1: U1.27 (A1), U4.11 (A1)
A2: U1.30 (A2), U4.10 (A2)
A3: U1.29 (A3), U4.9 (A3)
A4: U1.32 (A4), U4.8 (A4)
A5: U1.31 (A5), U4.7 (A5)
A6: U1.22 (A6), U4.6 (A6)
A7: U1.21 (A7), U4.5 (A7)
A8: U1.24 (A8), U4.27 (A8)
A9: U1.17 (A9), U4.26 (A9)
A10: U1.20 (A10), U4.23 (A10)
A11: U1.19 (A11), U4.25 (A11)
A12: U1.23 (A12), U4.4 (A12)
A13: U1.26 (A13), U4.28 (A13)
A14: U1.25 (A14), U2.1 (OE), U5.2 (A0)
D0: U1.34 (D0), U2.2 (D0), U4.13 (D0)
D1: U1.33 (D1), U2.3 (D1), U4.14 (D1)
D2: U1.36 (D2), U2.4 (D2), U4.15 (D2)
D3: U1.35 (D3), U2.5 (D3), U4.17 (D3)
D4: U1.38 (D4), U2.6 (D4), U4.18 (D4)
D5: U1.37 (D5), U2.7 (D5), U4.19 (D5)
D6: U1.40 (D6), U2.8 (D6), U4.20 (D6)
D7: U1.39 (D7), U2.9 (D7), U4.21 (D7)
GND: C2.2, C3.2, C4.2, C5.2, R1.1, R2.1, R3.1, R4.1, R5.1, U1.41 (GND), U1.43 (GND), U2.10 (GND), U4.16 (GND), U5.8 (GND), U5.13 (A1), U5.14 (A0), U5.15 (E)
unnamed: U1.44 (SW1), U1.46 (SW2)
unnamed: U2.11 (Cp), U5.5 (O1)
unnamed: R1.2, U2.19 (Q0), U4.29 (A14)
unnamed: R2.2, U2.18 (Q1), U4.3 (A15)
unnamed: R3.2, U2.17 (Q2), U4.2 (A16)
unnamed: R4.2, U2.16 (Q3), U4.30 (A17)
unnamed: R5.2, U2.15 (Q4), U4.1 (A18)
unnamed: SW1.2, U4.22 (/CE)
unnamed: U4.31 (/WE), U5.4 (O0)
/RD: U1.14 (/RD), U4.24 (/OE)
/SLTSL: SW1.3, U1.4 (/SLTSL), U5.3 (A1)
/WR: U1.13 (/WR), U5.1 (E)

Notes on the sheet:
/WR (/E)
/SLTSL (A1)
A14(A0)
Cp(O1)
/WE(O0)
BANK0: 4000-7FFF BANK1: 8000-BFFF BANK0 is BANK#0 fixed. BANK1 Register: 4000-7FFF (Mirror C000-FFFF) Initial value is undefined
4.7kΩ

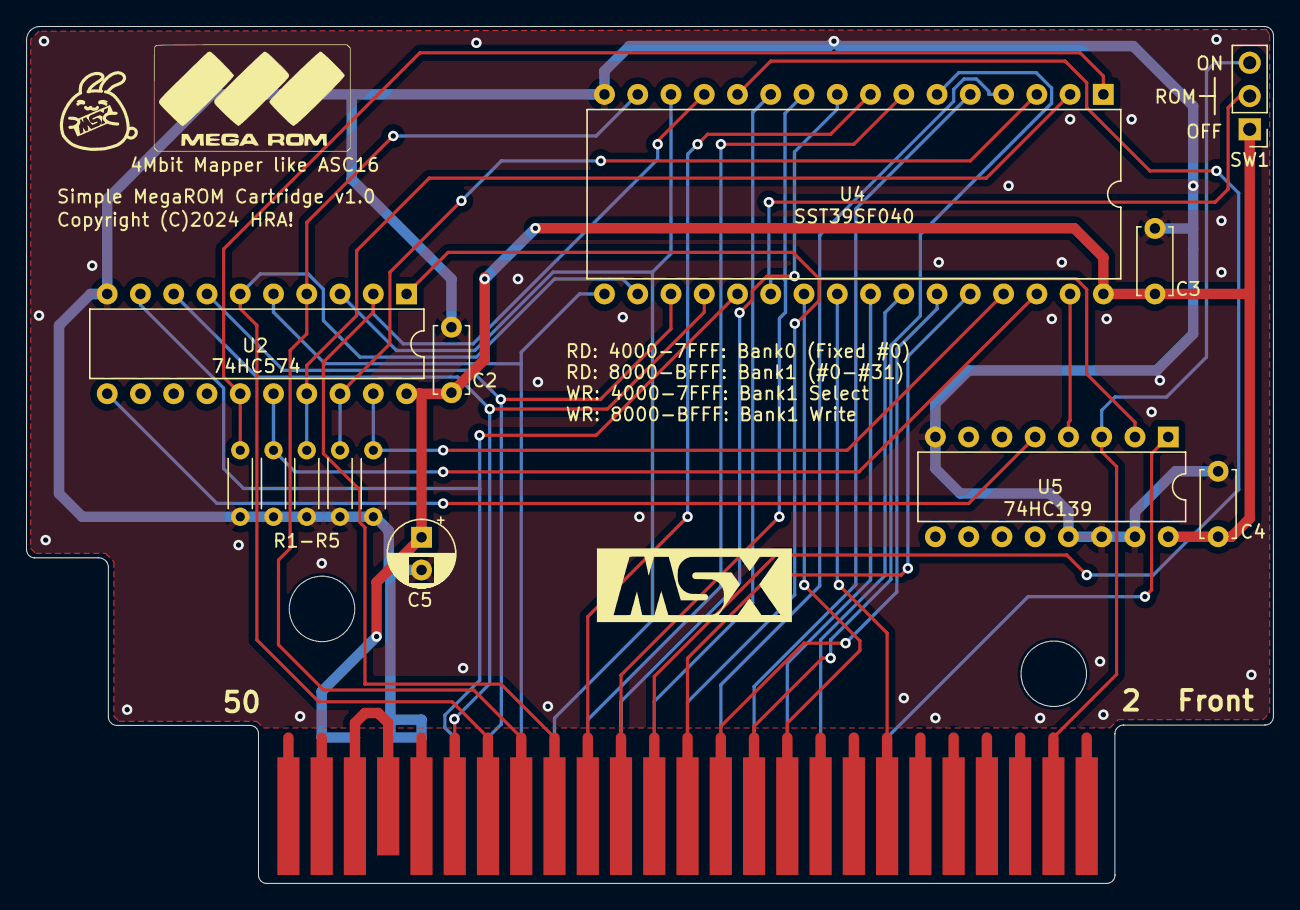
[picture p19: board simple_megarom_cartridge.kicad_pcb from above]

Board: 2 copper layers, 95.2 x 65.4 mm, 14 parts (0 on the bottom side), 37 nets.

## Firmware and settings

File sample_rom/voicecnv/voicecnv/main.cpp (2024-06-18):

// --------------------------------------------------------------------
//	音声データ変換ツール
// --------------------------------------------------------------------

#include <cstdio>
#include <cstdlib>
#include <cstdint>
#include <cstring>

using namespace std;

#define PROGRAM_SIZE 6144
#define ROM_SIZE (1024 * 512)

typedef struct {
	int32_t		riff_id;
	int32_t		riff_size;
	int32_t		riff_type;
	int32_t		fmt_chank_id;
	int32_t		fmt_chank_size;
	int16_t		type;
	int16_t		channel;
	int32_t		sample;
	int32_t		byte_size;
	int16_t		sample_bytes;
	int16_t		sample_bits;
	int32_t		data_chank_id;
	int32_t		data_chank_size;
} WAV_HEADER_T;

// --------------------------------------------------------------------
static int convert_one( int d ) {
	//                                0    1    2     3     4     5     6     7     8     9     10     11     12     13     14     15
	static const int psg_level[] = { 362, 511, 724, 1023, 1448, 2047, 2896, 4095, 5792, 8191, 11585, 16383, 23170, 32767, 46340, 65535 };
	int i;

	d = d * 2 + 32768;
	for( i = 0; i < 15; i++ ) {
		if( d < psg_level[i] ) {
			break;
		}
	}
	return i;
}

// --------------------------------------------------------------------
static void convert( void ) {
	char s_buffer[128];
	FILE* p_file;
	int16_t* p_data;
	int samples;
	static WAV_HEADER_T header;
	static uint8_t result[ ROM_SIZE - PROGRAM_SIZE ];
	int i, l, h, s;

	sprintf( s_buffer, "voice.wav" );
	printf( "Read '%s' ... ", s_buffer );
	p_file = fopen( s_buffer, "rb" );
	if( p_file == NULL ) {
		printf( "[ERROR] Cannot open the '%s'.\n", s_buffer );
		exit( 1 );
	}
	fread( &header, sizeof( header ), 1, p_file );
	samples = ( header.data_chank_size - 16 ) / 2;
	p_data = (int16_t*)malloc( samples * 2 );
	if( p_data == NULL ) {
		printf( "[ERROR] Not enough memory.\n" );
		exit( 1 );
	}
	fread( p_data, samples, 2, p_file );
	fclose( p_file );
	printf( "OK\n" );
	printf( "Samples = %d\n", samples );
	printf( "Wave memory size = %d\n", (int)sizeof( result ) );

	memset( result, 0, sizeof( result ) );
	for( i = 0; i < sizeof(result); i++ ) {
		//	下位4bit
		s = (int)( (long long)(i * 2 + 0) * samples / (sizeof(result) * 2) );
		if( s >= samples ) {
			s = samples - 1;
		}
		l = convert_one( p_data[s] );
		//	上位4bit
		s = (int)( (long long)(i * 2 + 1) * samples / (sizeof(result) * 2) );
		if( s >= samples ) {
			s = samples - 1;
		}
		printf( "%d --> %d\r", s, i );
		h = convert_one( p_data[s] );
		//	result
		result[i] = (uint8_t)(l | ( h << 4 ));
	}
	printf( "%d --> %d\n", s, i );

	sprintf( s_buffer, "voise.bin" );
	printf( "Write '%s' ... ", s_buffer );
	p_file = fopen( s_buffer, "wb" );
	if( p_file == NULL ) {
		printf( "[ERROR] Cannot create the '%s'.\n", s_buffer );
		exit( 1 );
	}
	printf( "OK\n" );
	fwrite( result, sizeof(result), 1, p_file );
	fclose( p_file );
}

// --------------------------------------------------------------------
int main( int argc, char* argv[] ) {

	printf( "Voice Converter\n" );
	printf( "==========================================================\n" );
	printf( "2024 Copyright (C) t.hara\n" );

	convert();

	printf( "Completed.\n" );
	return 0;
}

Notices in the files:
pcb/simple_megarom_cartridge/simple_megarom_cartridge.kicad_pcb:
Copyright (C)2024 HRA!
